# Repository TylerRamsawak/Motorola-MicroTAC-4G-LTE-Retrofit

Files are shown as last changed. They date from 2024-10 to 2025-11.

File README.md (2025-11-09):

# Motorola-MicroTAC-4G-LTE-Retrofit DEPRECATED
<b>Obsolete and no longer works in the real world. I am working on a revision using a quectel bg modem instead. I recommend you stay away from SIMCOM in the future.</b>

A PCB to replace the old hardware inside of a Motorola MicroTAC 9800X and like models that share the same housing with a 4G LTE modem.

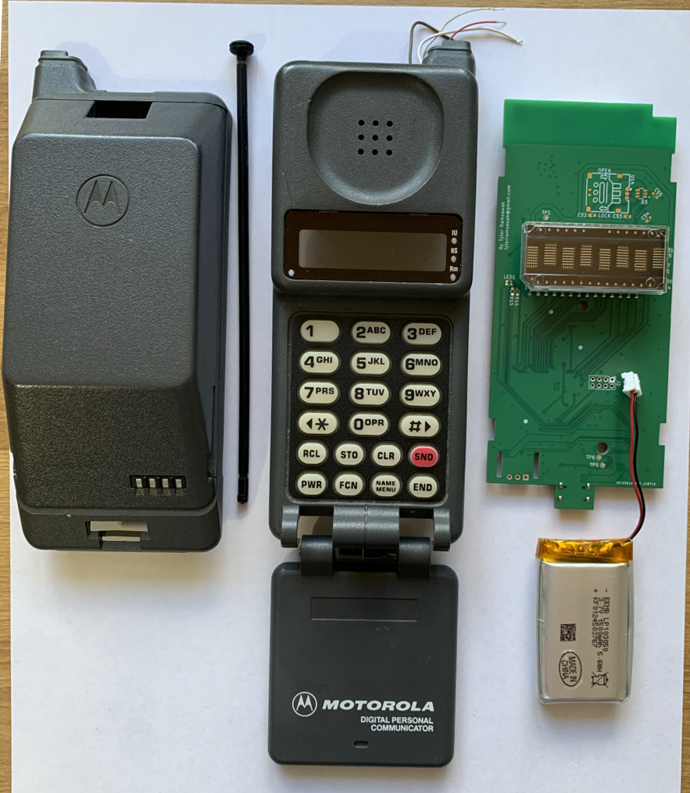
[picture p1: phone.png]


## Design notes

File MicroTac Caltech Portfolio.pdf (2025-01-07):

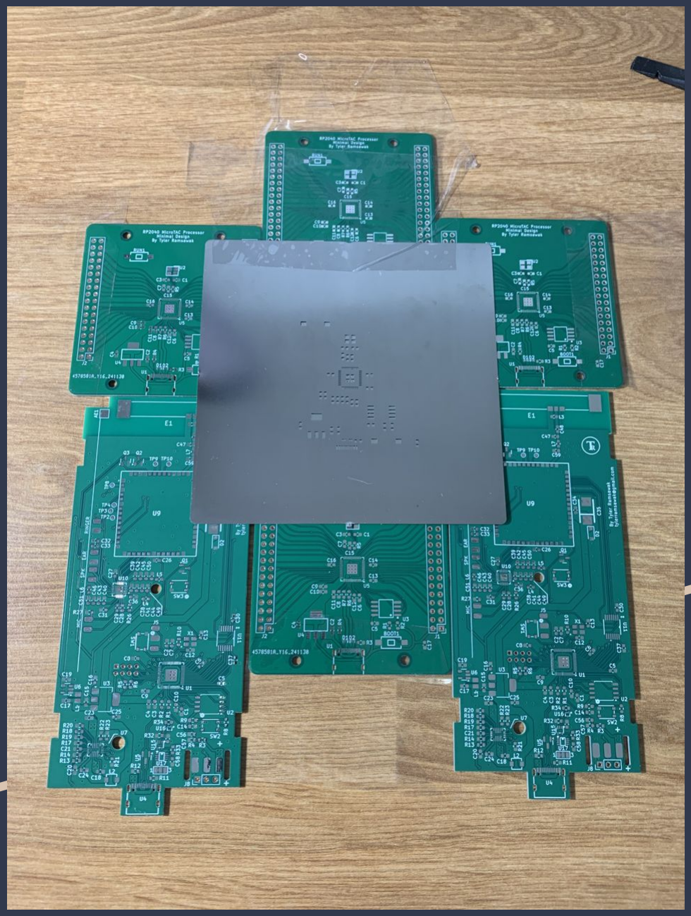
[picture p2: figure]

MicroTAC Assembly Process

### 1. Stencil Framing

First, I frame the prototype by taping down extra PCBs
around it.
This ensures that the
prototype won’t shift around during solder paste
application.

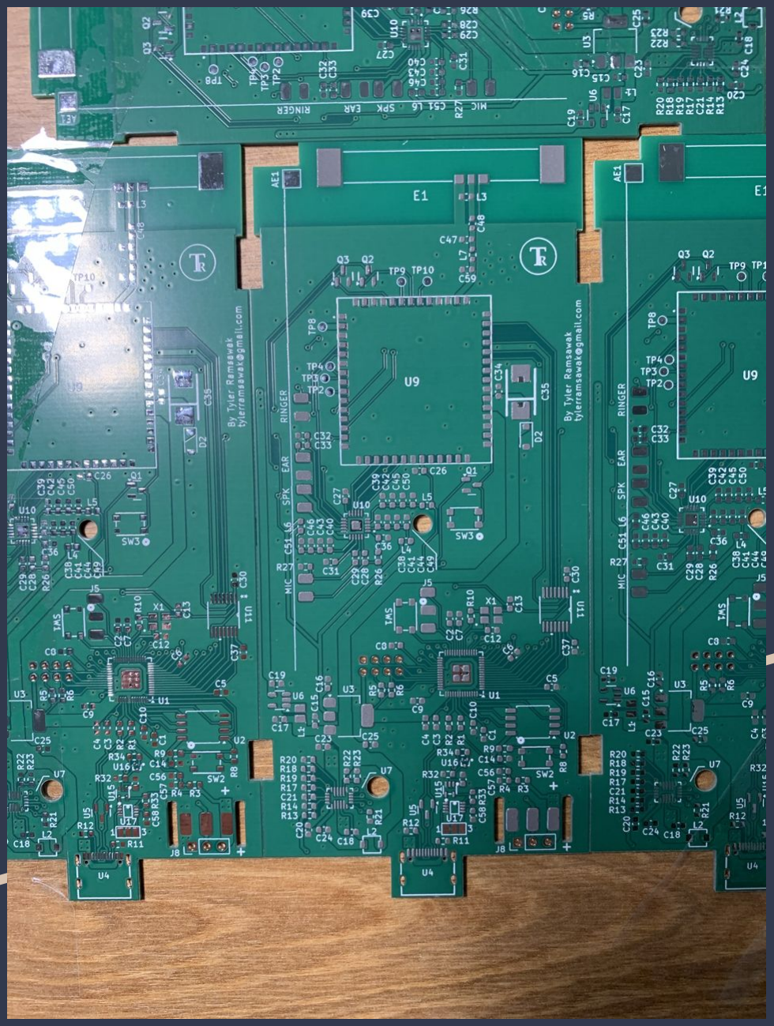
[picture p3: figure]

MicroTAC Assembly Process

### 2. Applying Solder Paste

Using a metal squeegee, I
pull solder paste across the stencil that lays on top of the prototype.
This applies solder paste to the pads of the board.

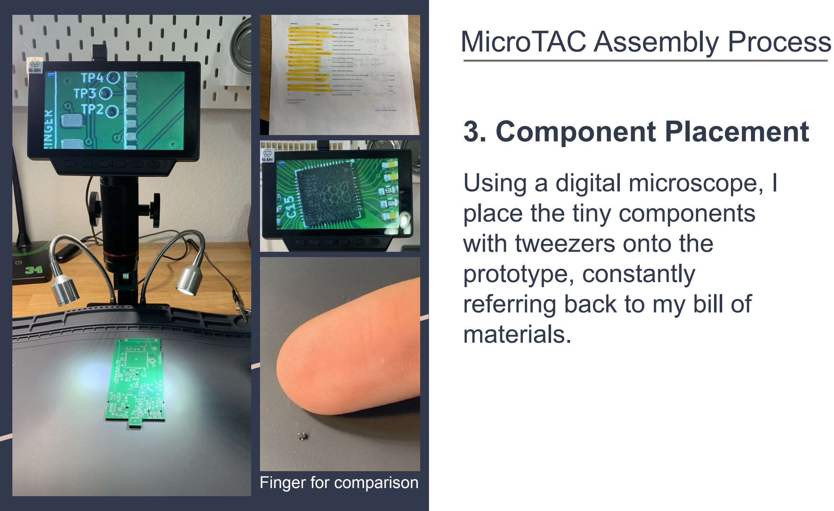
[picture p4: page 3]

MicroTAC Assembly Process

### 3. Component Placement

Using a digital microscope, I place the tiny components
with tweezers onto the
prototype, constantly
referring back to my bill of materials.

Finger for comparison

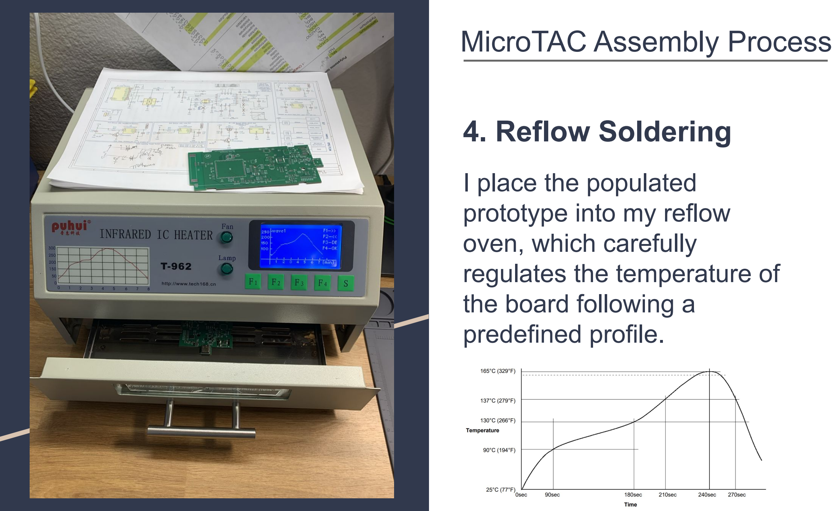
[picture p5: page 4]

MicroTAC Assembly Process

### 4. Reflow Soldering

I place the populated
prototype into my reflow
oven, which carefully
regulates the temperature of the board following a
predefined profile.

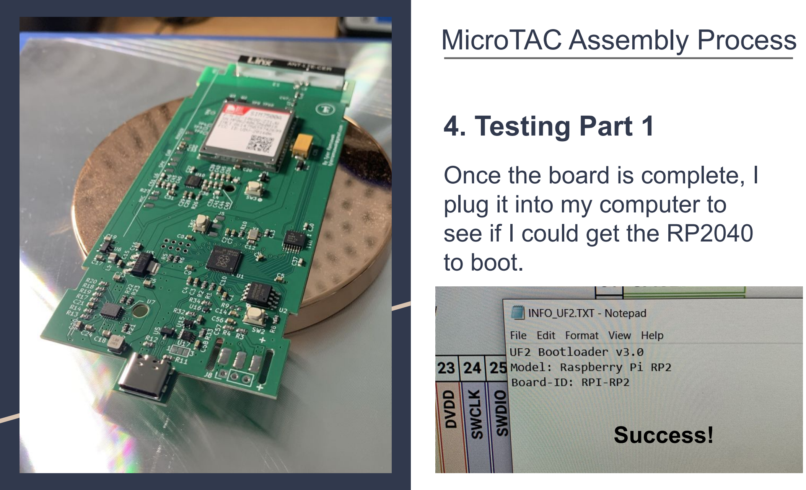
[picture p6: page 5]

MicroTAC Assembly Process

### 4. Testing Part 1

Once the board is complete, I plug it into my computer to see if I could get the RP2040 to boot.

Success!

MicroTAC Assembly Process

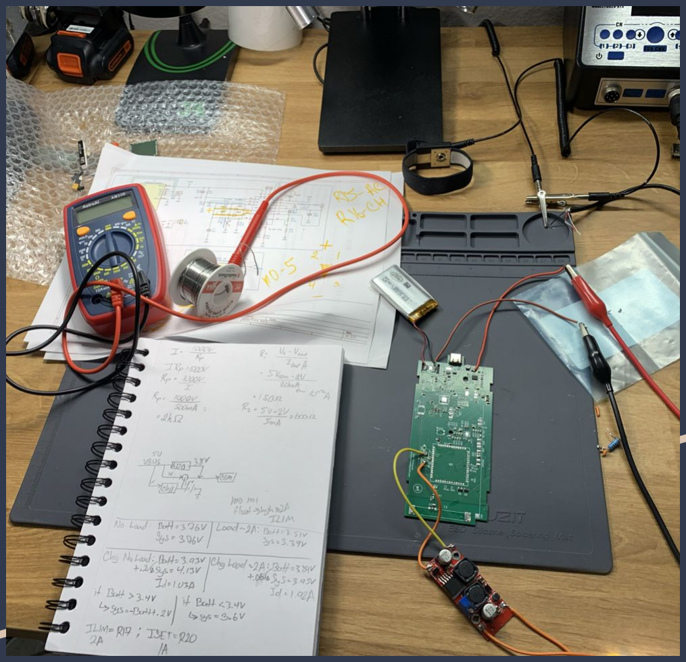
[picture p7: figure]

### 4. Testing Part 2

On a separate barebones
prototype, I aggressively test the charging circuitry and battery protection features by simulating a 2A continuous load condition and recording data with a multimeter.
I compare this data with the formulas in the PMIC
datasheet.

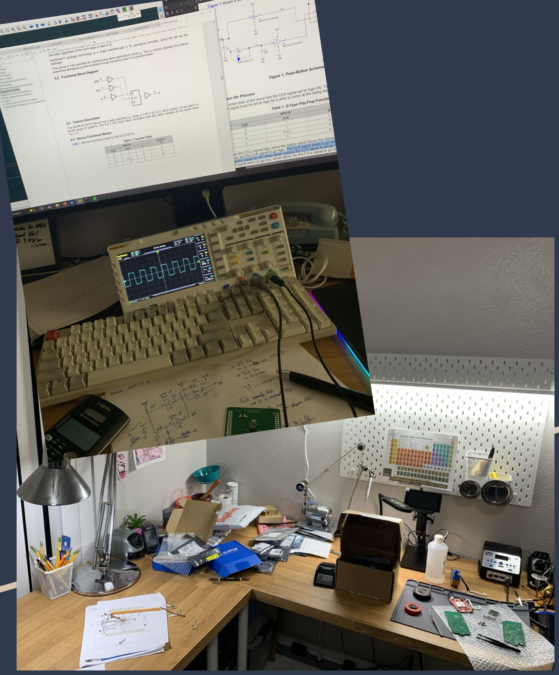
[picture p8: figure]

MicroTAC Assembly Process

### 5. Cleaning

My lab turns into a mess after the assembly and debugging. So, I usually take the rest of the night to clean up and
reorganize my equipment.

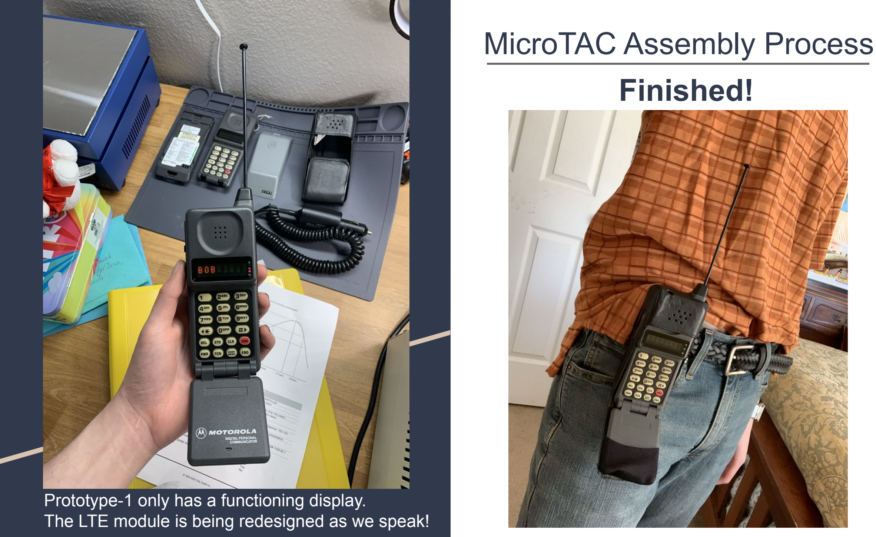
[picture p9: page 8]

MicroTAC Assembly Process

Prototype-1 only has a functioning display.
The LTE module is being redesigned as we speak!

Finished!

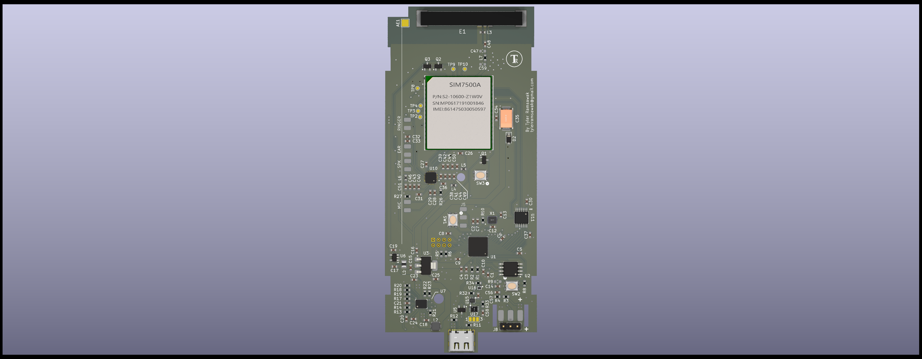
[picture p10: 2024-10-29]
3D_front_populated.png

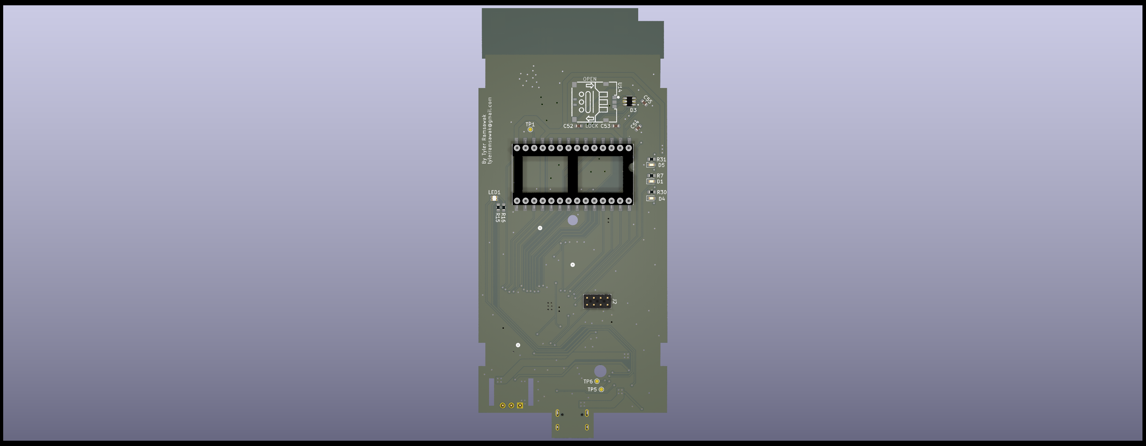
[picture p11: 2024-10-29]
3D_back_populated.png

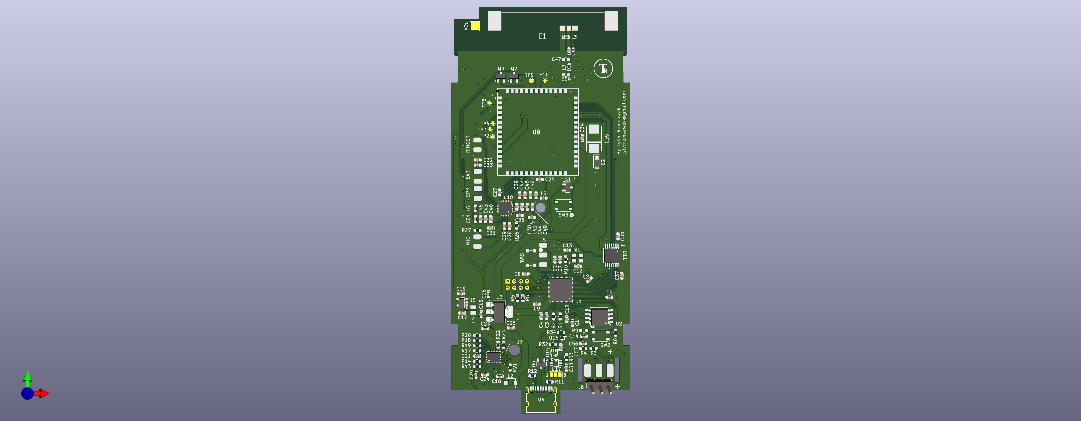
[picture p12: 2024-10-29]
3D_front_np.png

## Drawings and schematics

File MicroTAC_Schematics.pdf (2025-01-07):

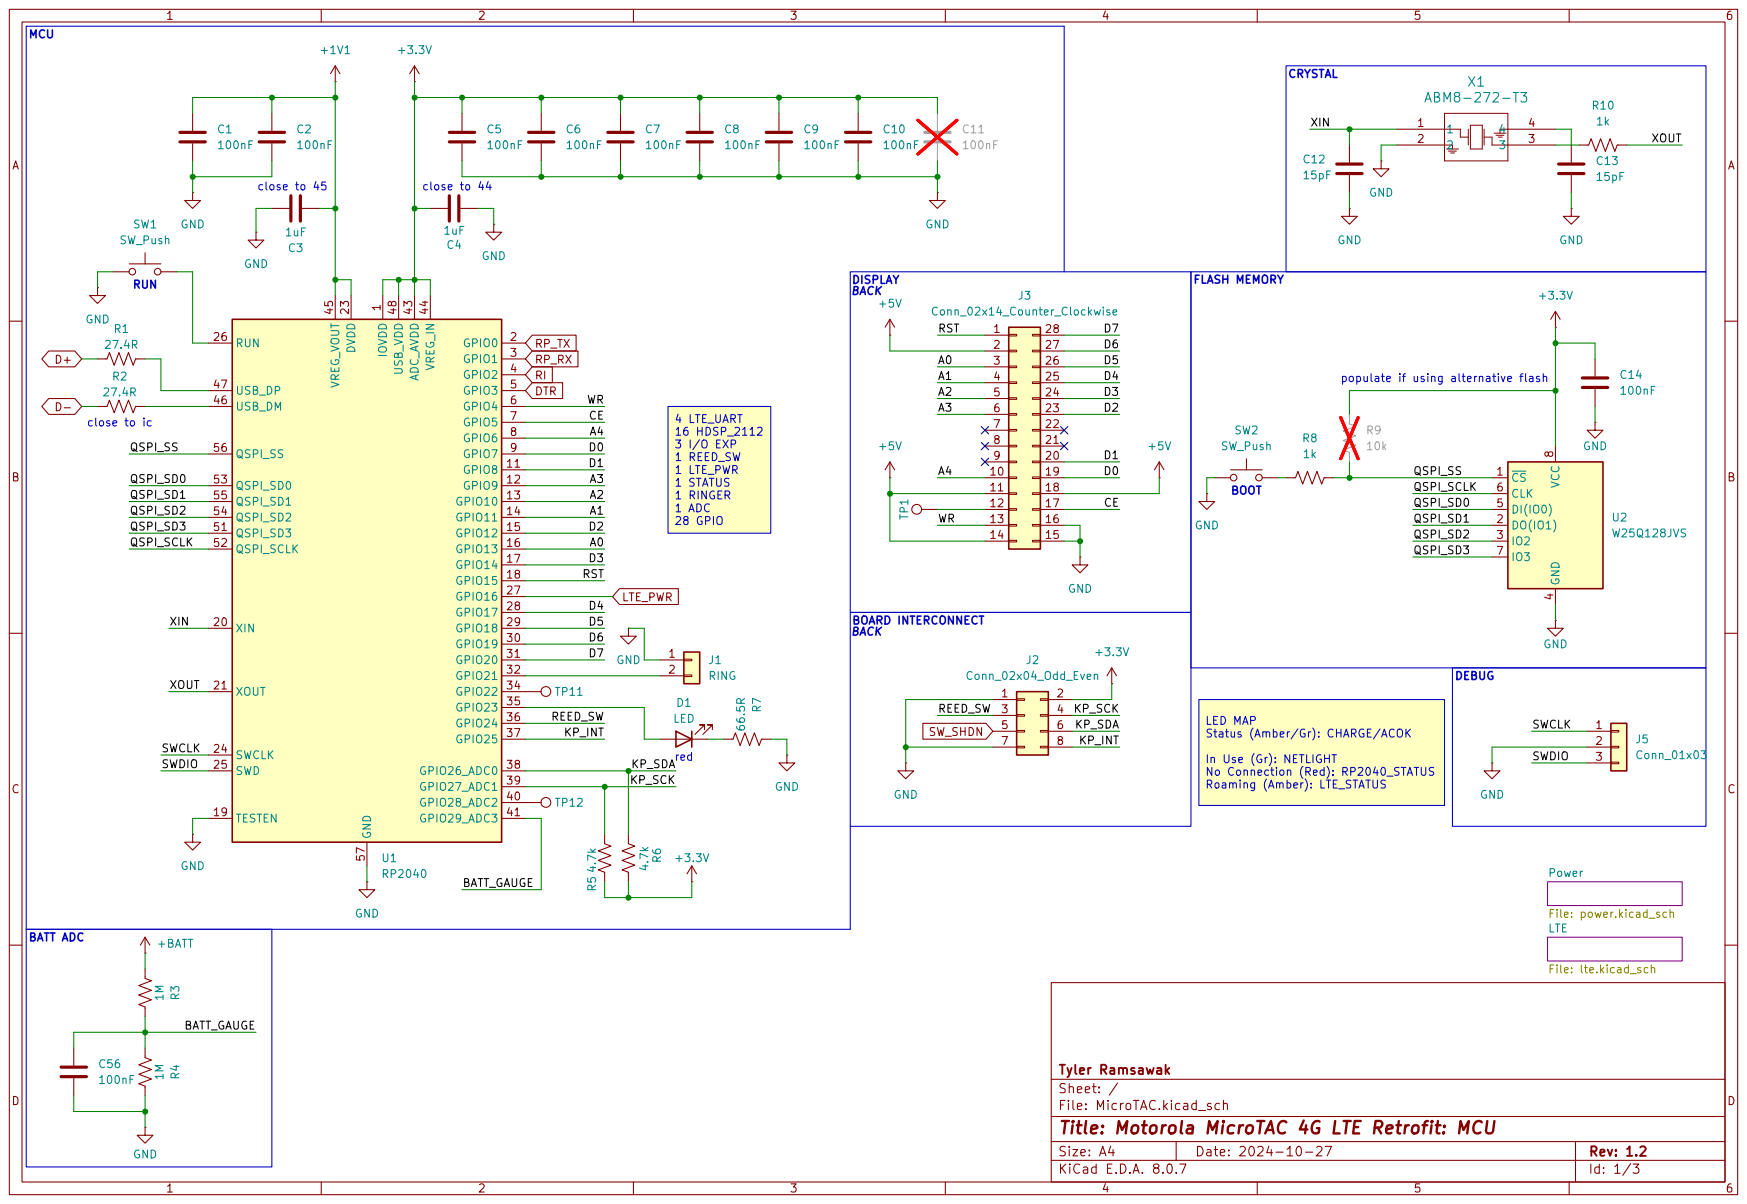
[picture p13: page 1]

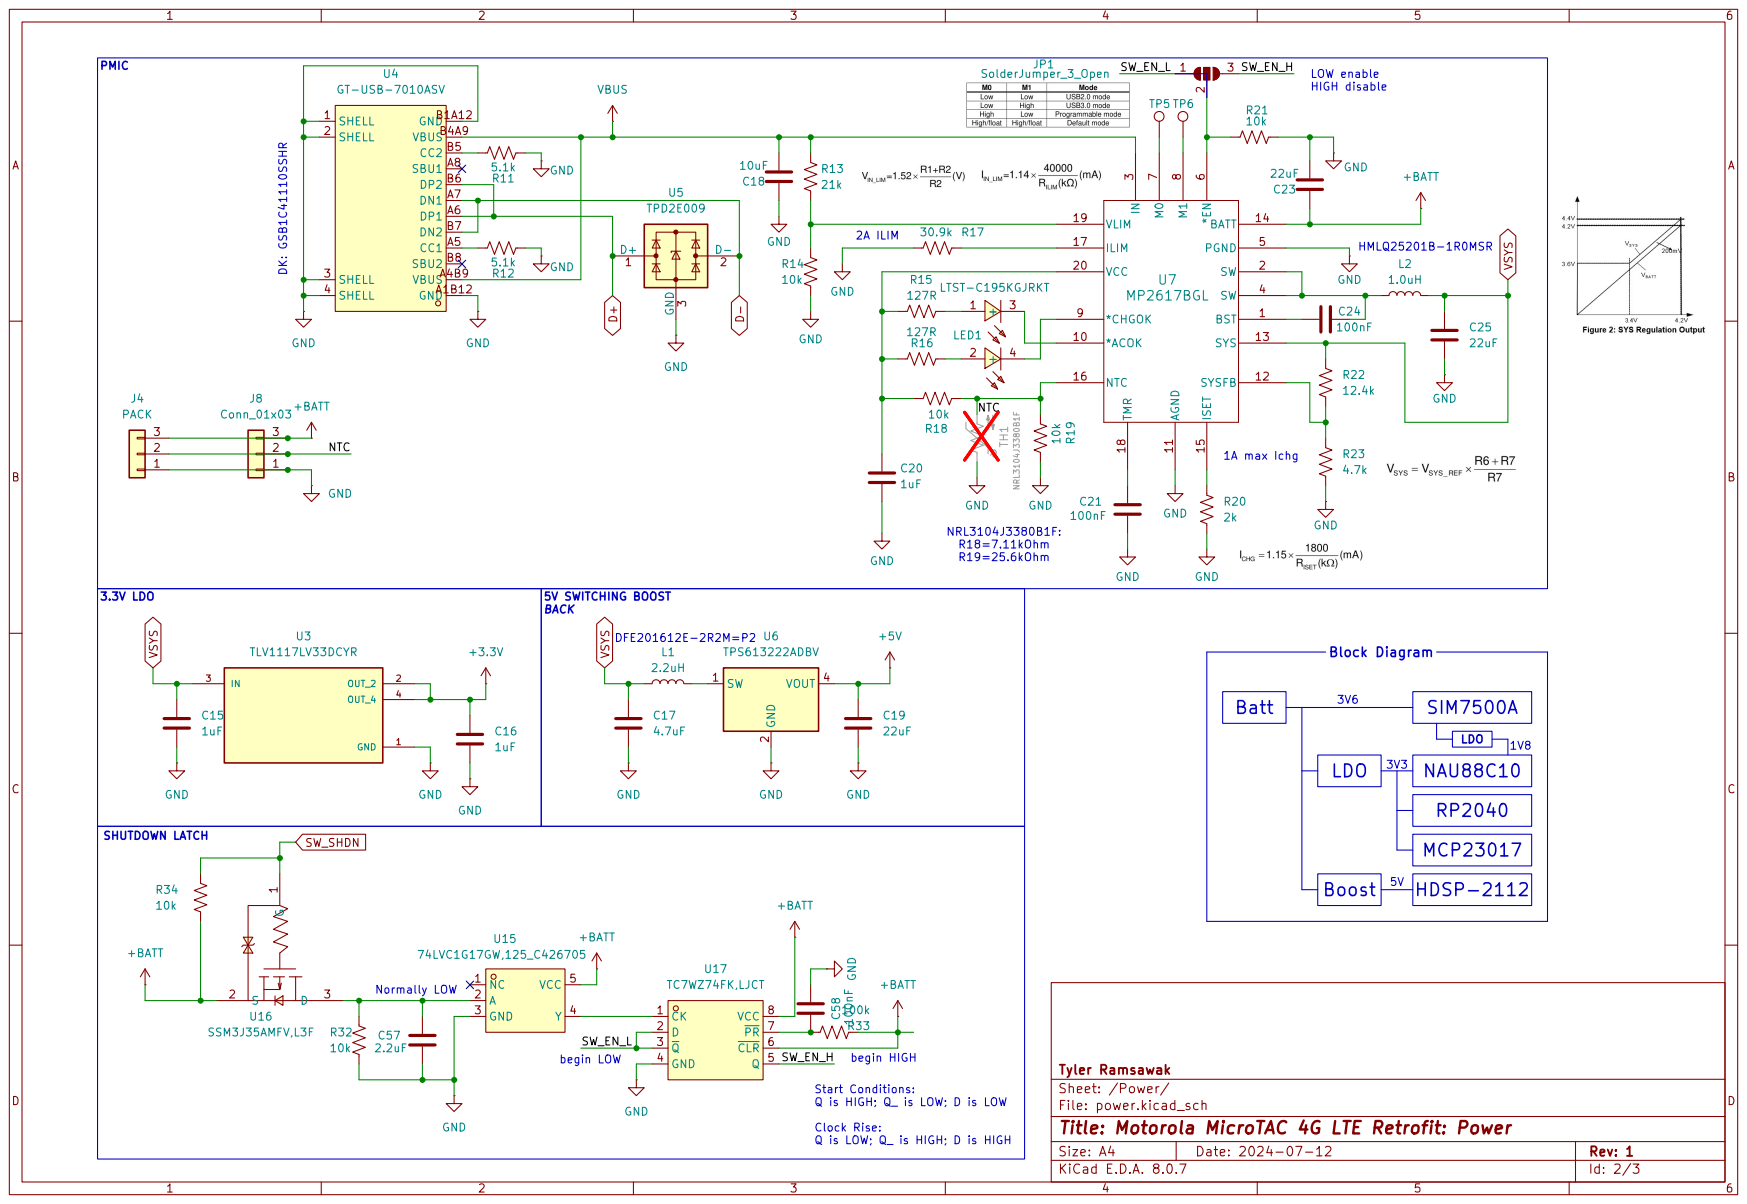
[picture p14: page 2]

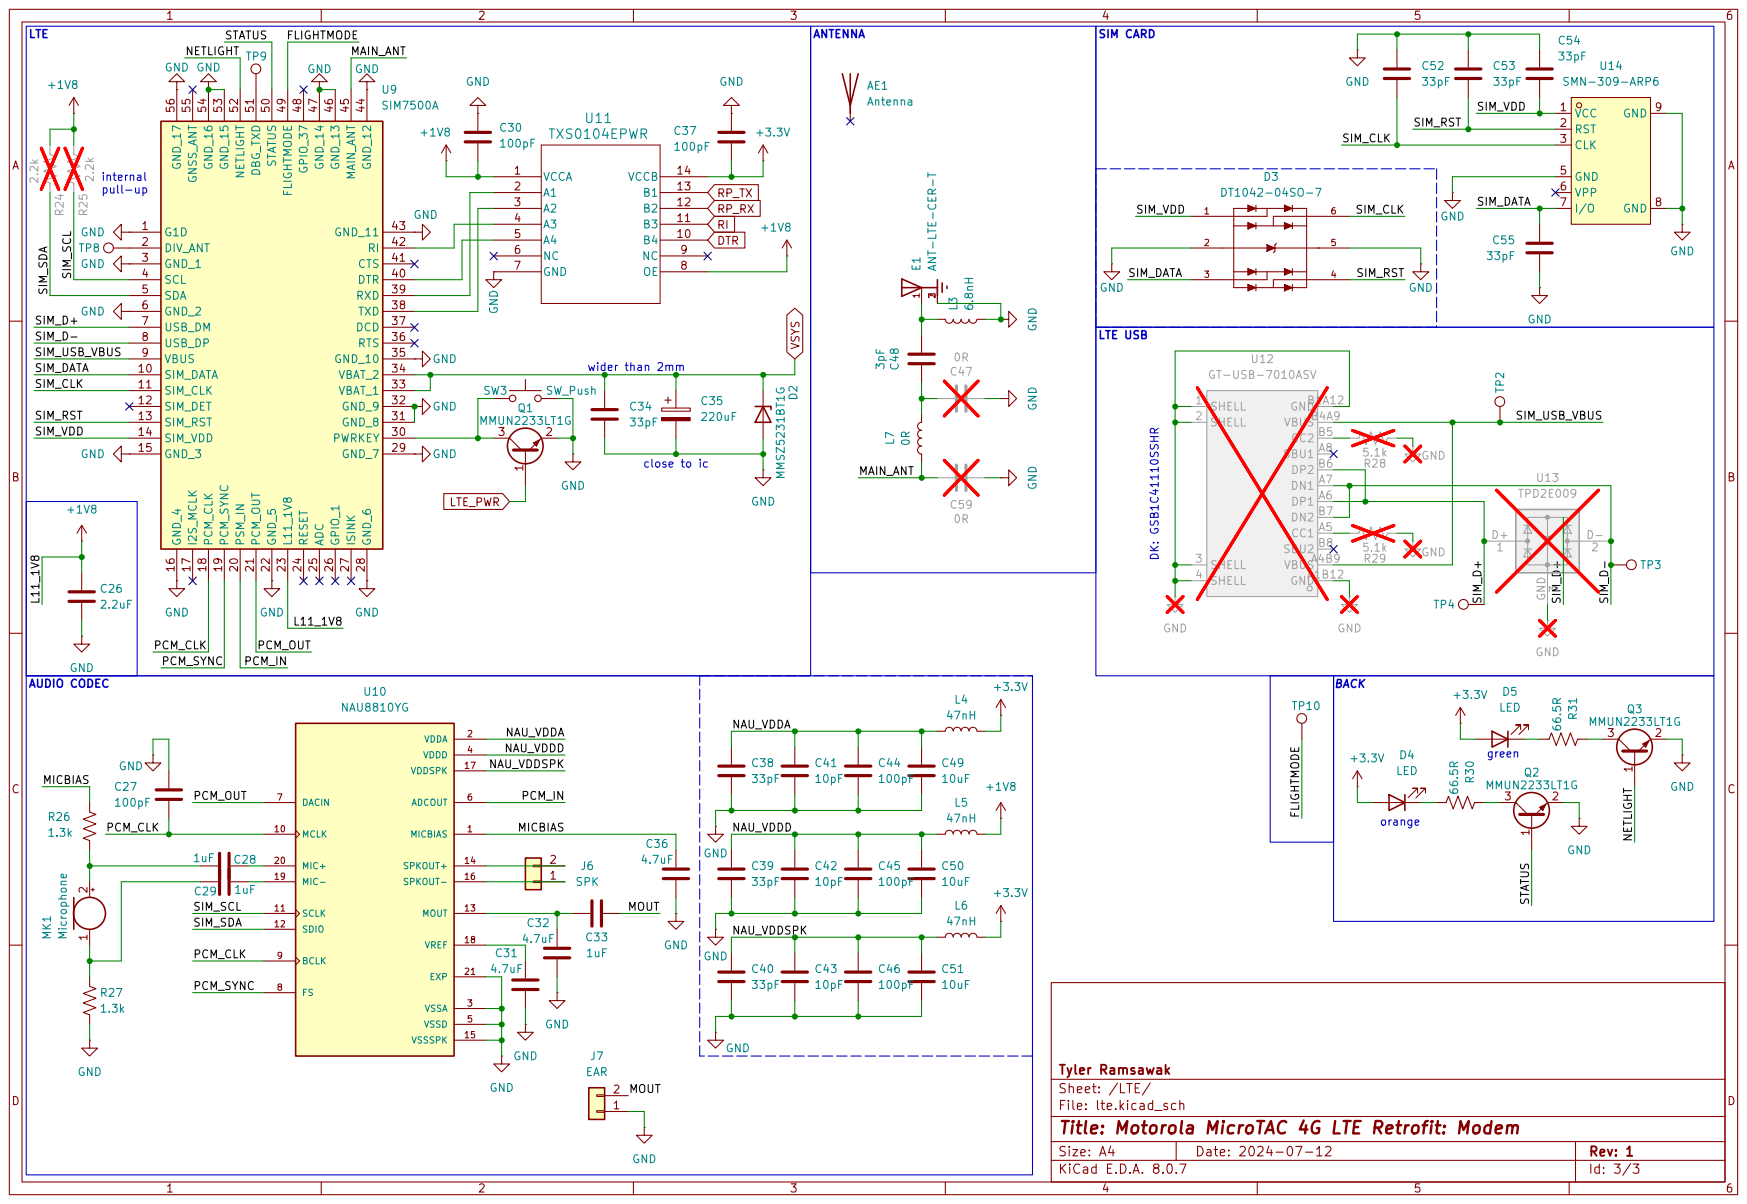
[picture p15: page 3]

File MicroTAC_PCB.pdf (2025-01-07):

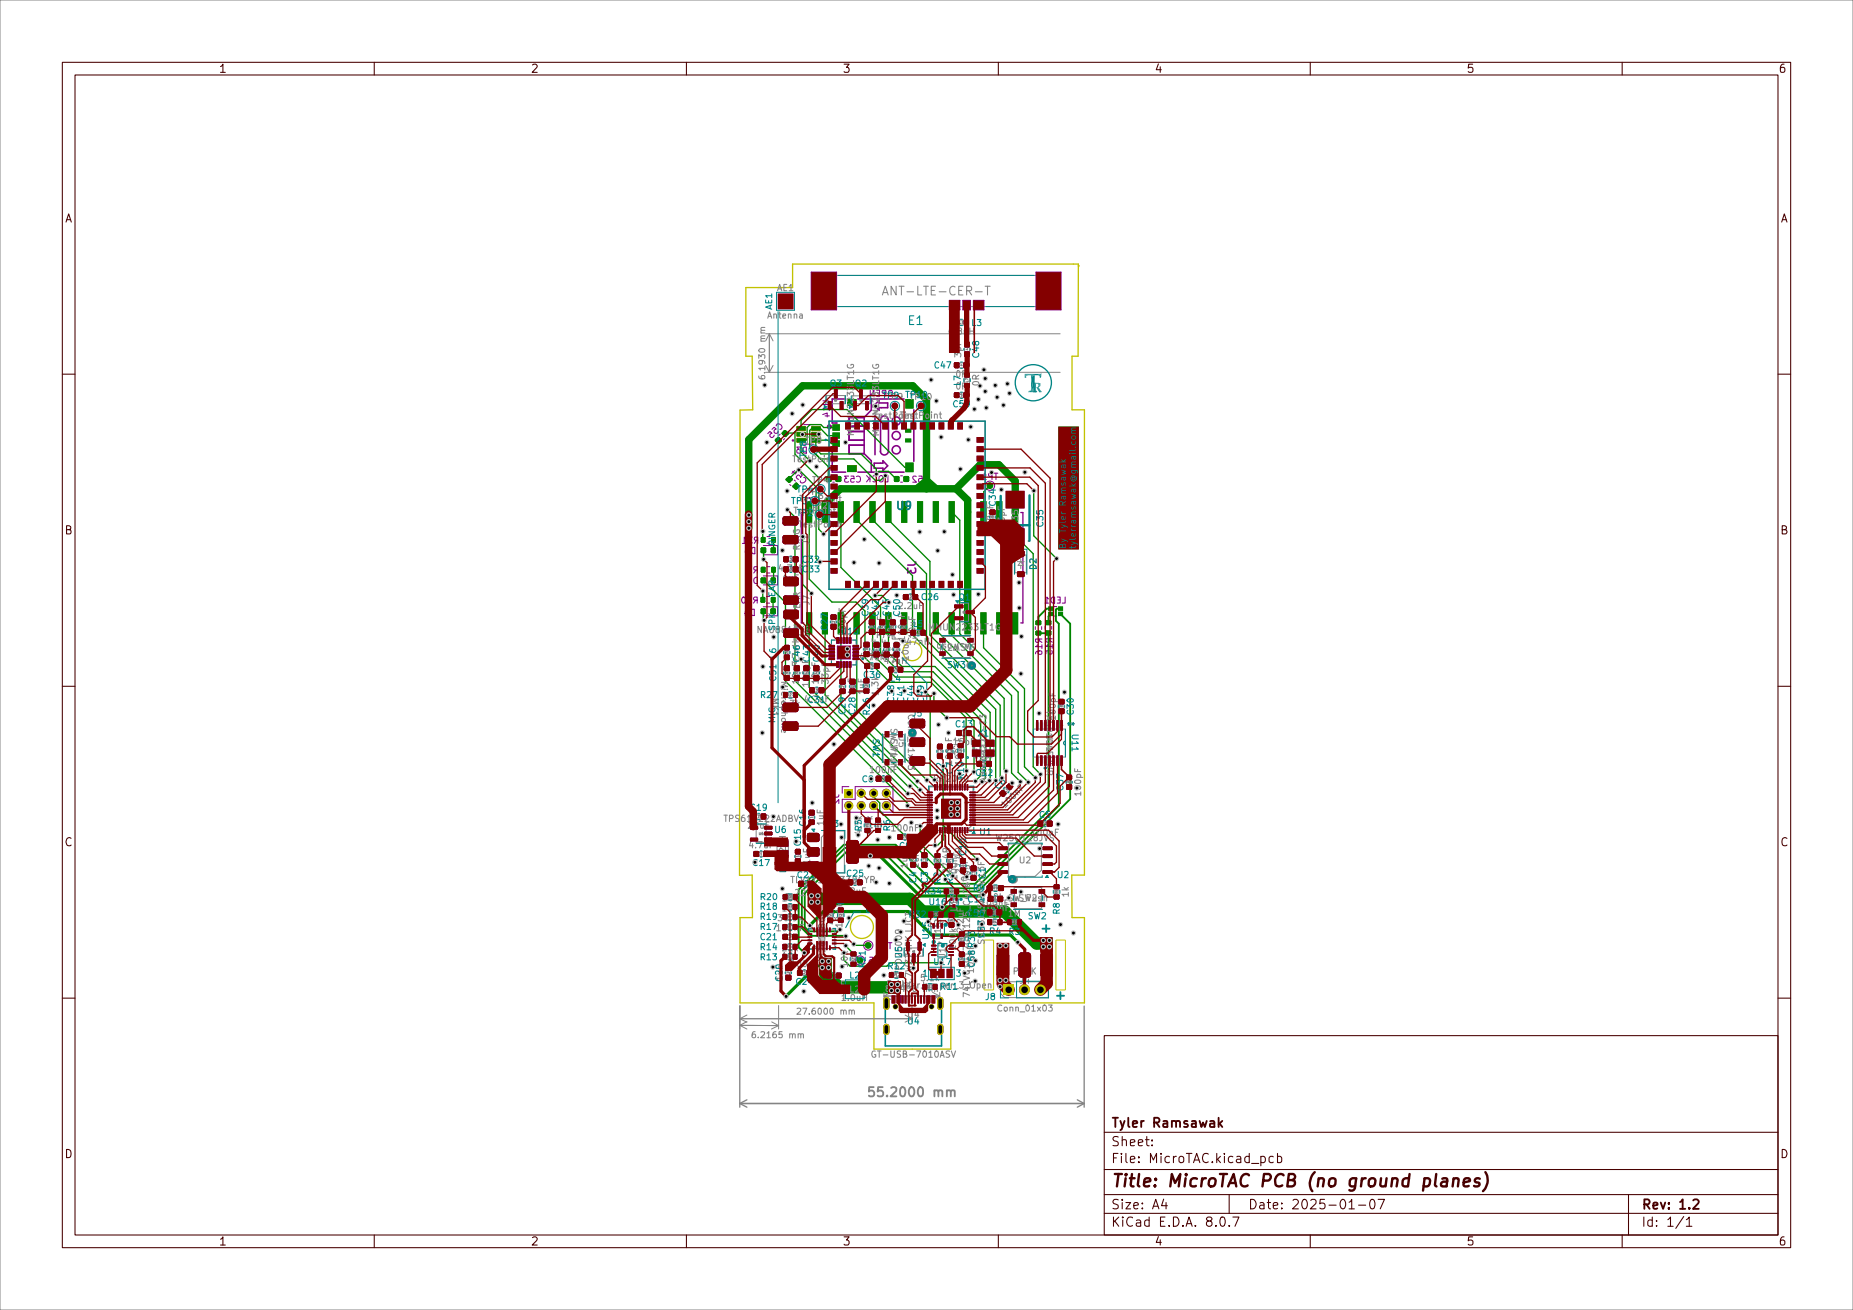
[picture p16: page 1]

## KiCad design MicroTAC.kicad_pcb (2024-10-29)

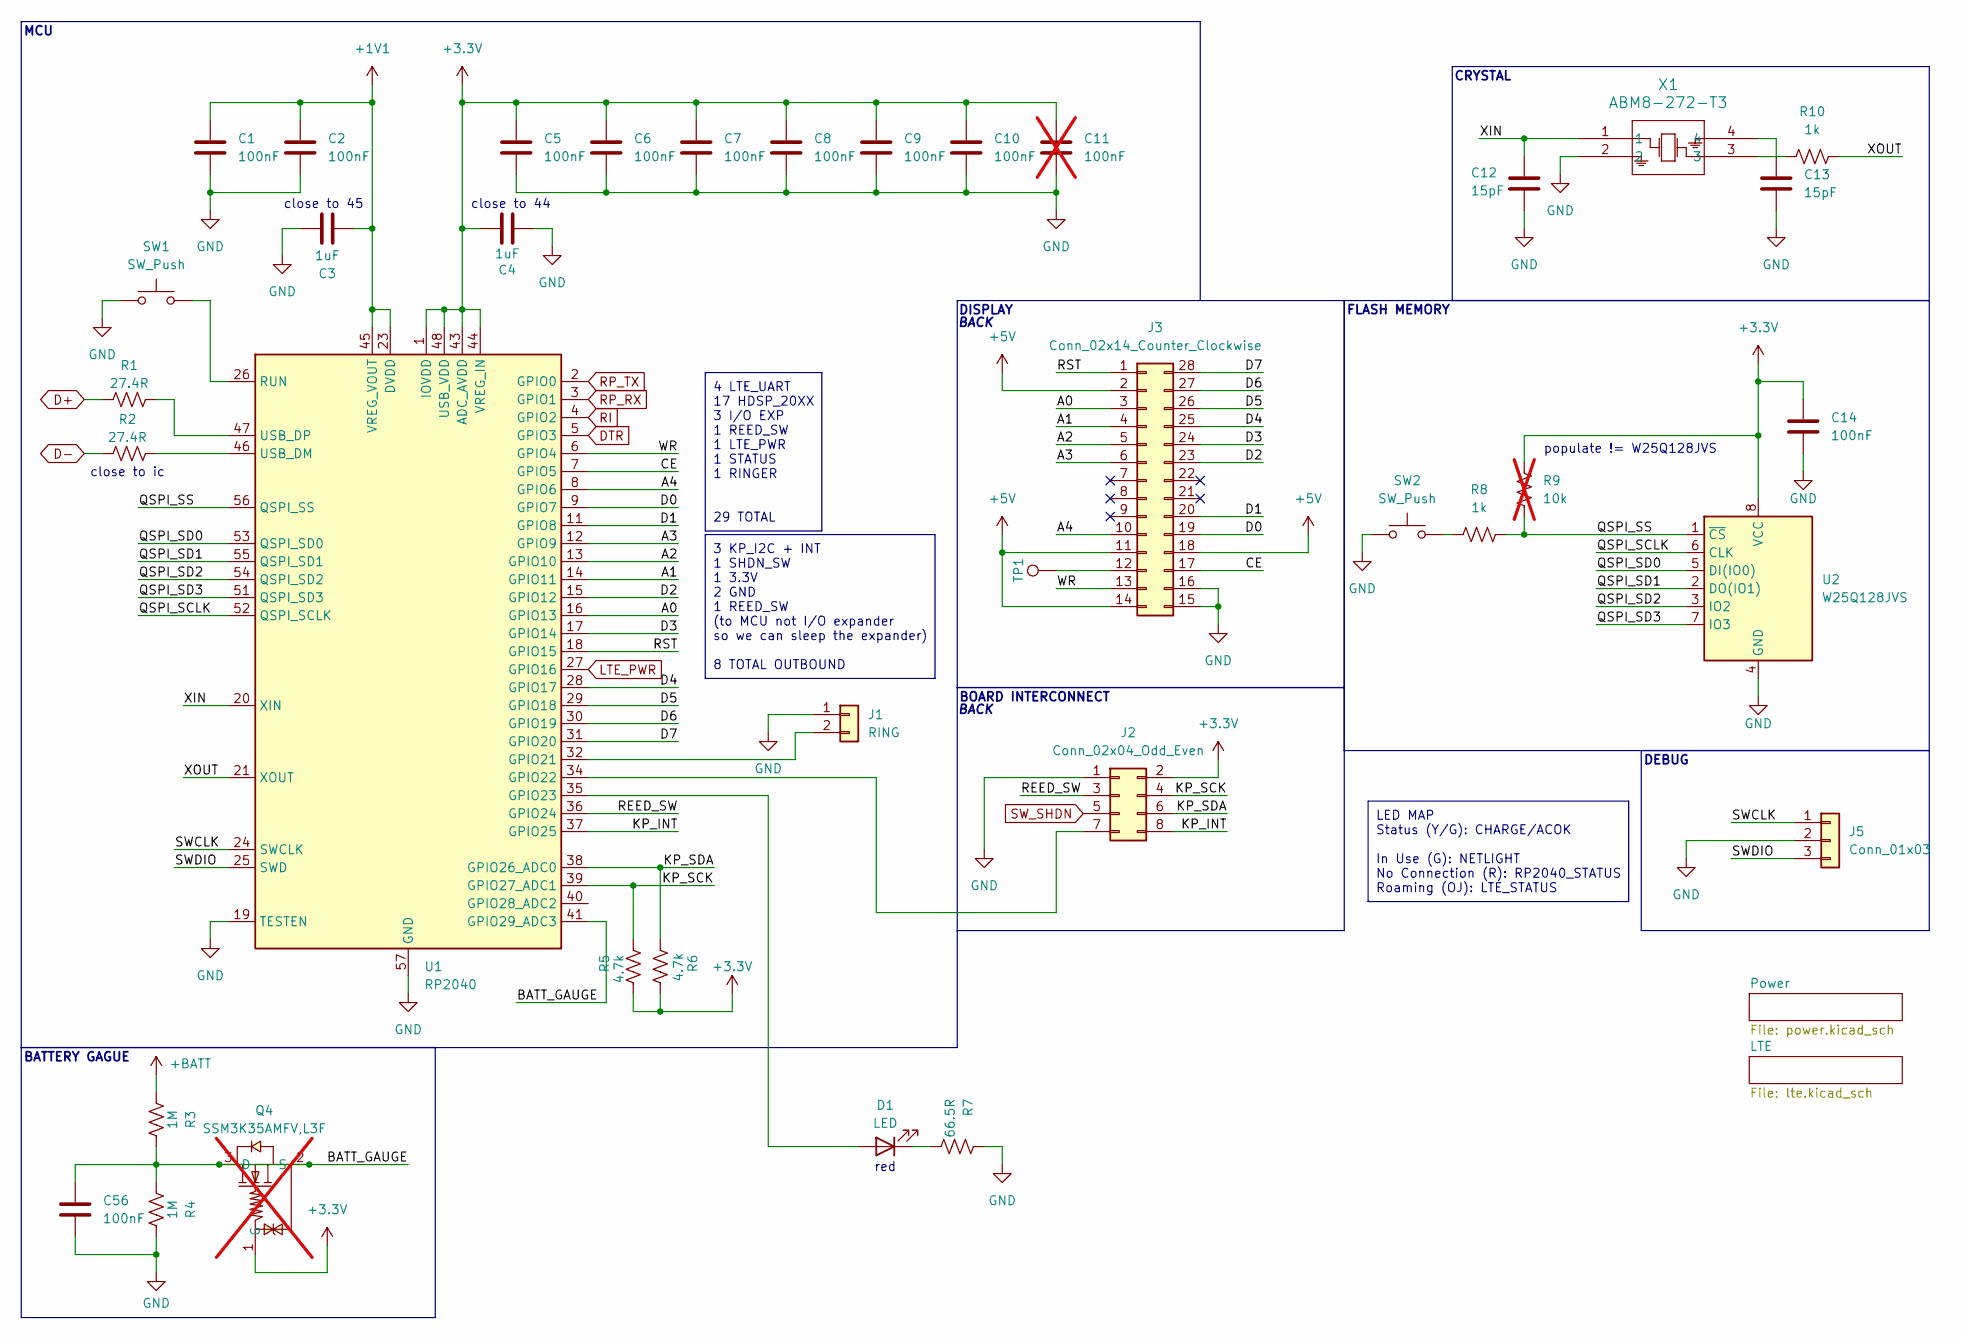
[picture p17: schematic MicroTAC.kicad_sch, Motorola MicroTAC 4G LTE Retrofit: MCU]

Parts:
C1, C2, C5, C6, C7, C8, C9, C10, C14, C56: 100nF; C_0603_1608Metric; LCSC Part # C1591
C3, C4: 1uF; C_0603_1608Metric; LCSC Part # C59782
C11: 100nF; C_0603_1608Metric_Pad1.08x0.95mm_HandSolder; LCSC Part # C1591; not fitted
C12, C13: 15pF; C_0603_1608Metric; LCSC Part # C346207
D1: LED; LED_0603_1608Metric; LCSC Part # C125099
J1: RING; MicroTAC Peripherals
J2: Conn_02x04_Odd_Even; PinHeader_2x04_P2.00mm_Vertical; LCSC Part # C917609
J3: Conn_02x14_Counter_Clockwise; 1108762841105101
J5: Conn_01x03; MicroTAC Debug
Q4: SSM3K35AMFV,L3F; SOT-723_L1.2-W0.8-P0.40-LS1.2-BR; LCSC Part C150155; not fitted
R1, R2: 27.4R; R_0603_1608Metric; LCSC Part # C185346
R3, R4: 1M; R_0603_1608Metric; LCSC Part # C14675
R5, R6: 4.7k; R_0603_1608Metric; LCSC Part # C99782
R7: 66.5R; R_0603_1608Metric; LCSC Part # C245995
R8, R10: 1k; R_0603_1608Metric; LCSC Part # C22548
R9: 10k; R_0603_1608Metric_Pad0.98x0.95mm_HandSolder; not fitted
SW1, SW2: SW_Push; SW4_PTS815_SJM_250_SMTR_LFS_CNK; LCSC Part # C2689510
TP1: TestPoint; TestPoint_Pad_D1.0mm
U1: RP2040; QFN-56-1EP_7x7mm_P0.4mm_EP3.2x3.2mm; LCSC Part # C2040
U2: W25Q128JVS; SOIC-8_5.23x5.23mm_P1.27mm; LCSC Part # C97521
X1: ABM8-272-T3; ABM8-272-T3_ABR; LCSC Part # C20625731

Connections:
+1V1: C1.1, C2.1, C3.1, U1.23 (DVDD), U1.45 (VREG_VOUT), U1.50 (DVDD)
+3.3V: C4.1, C5.1, C6.1, C7.1, C8.1, C9.1, C10.1, C11.1, C14.1, J2.2, Q4.1 (G), R5.2, R6.2, R9.1, U1.1 (IOVDD), U1.10 (IOVDD), U1.22 (IOVDD), U1.33 (IOVDD), U1.42 (IOVDD), U1.43 (ADC_AVDD), U1.44 (VREG_IN), U1.48 (USB_VDD), U1.49 (IOVDD), U2.8 (VCC); also elsewhere on the board
+5V: J3.2, J3.11, J3.14, J3.18; also elsewhere on the board
+BATT: R3.1; also elsewhere on the board
/A0: J3.3, U1.16 (GPIO13)
/A1: J3.4, U1.14 (GPIO11)
/A2: J3.5, U1.13 (GPIO10)
/A3: J3.6, U1.12 (GPIO9)
/A4: J3.10, U1.8 (GPIO6)
/BATT_GAUGE: C56.1, Q4.2 (S), Q4.3 (D), R3.2, R4.1, U1.41 (GPIO29_ADC3)
/CE: J3.17, U1.7 (GPIO5)
/D0: J3.19, U1.9 (GPIO7)
/D1: J3.20, U1.11 (GPIO8)
/D2: J3.23, U1.15 (GPIO12)
/D3: J3.24, U1.17 (GPIO14)
/D4: J3.25, U1.28 (GPIO17)
/D5: J3.26, U1.29 (GPIO18)
/D6: J3.27, U1.30 (GPIO19)
/D7: J3.28, U1.31 (GPIO20)
/KP_INT: J2.8, U1.37 (GPIO25)
/KP_SCK: J2.4, R5.1, U1.39 (GPIO27_ADC1)
/KP_SDA: J2.6, R6.1, U1.38 (GPIO26_ADC0)
/QSPI_SCLK: U1.52 (QSPI_SCLK), U2.6 (CLK)
/QSPI_SD0: U1.53 (QSPI_SD0), U2.5 (DI(IO0))
/QSPI_SD1: U1.55 (QSPI_SD1), U2.2 (DO(IO1))
/QSPI_SD2: U1.54 (QSPI_SD2), U2.3 (IO2)
/QSPI_SD3: U1.51 (QSPI_SD3), U2.7 (IO3)
/QSPI_SS: R8.2, R9.2, U1.56 (QSPI_SS), U2.1 (~CS)
/REED_SW: J2.3, U1.36 (GPIO24)
/RST: J3.1, U1.18 (GPIO15)
/SWCLK: J5.1, U1.24 (SWCLK)
/SWDIO: J5.3, U1.25 (SWD)
/WR: J3.13, U1.6 (GPIO4)
/XIN: C12.2, U1.20 (XIN), X1.1
/XOUT: R10.2, U1.21 (XOUT)
D+: R1.1; also elsewhere on the board
D-: R2.1; also elsewhere on the board
DTR: U1.5 (GPIO3); also elsewhere on the board
GND: C1.2, C2.2, C3.2, C4.2, C5.2, C6.2, C7.2, C8.2, C9.2, C10.2, C11.2, C12.1, C13.1, C14.2, C56.2, J1.1, J2.1, J3.15, J3.16, J5.2, R4.2, R7.2, SW1.1, SW2.1, U1.19 (TESTEN), U1.57 (GND), U2.4 (GND), X1.2; also elsewhere on the board
LTE_PWR: U1.27 (GPIO16); also elsewhere on the board
unnamed: C13.2, X1.4
unnamed: D1.2 (A), U1.35 (GPIO23)
unnamed: D1.1 (K), R7.1
unnamed: J1.2, U1.32 (GPIO21)
unnamed: J2.7, U1.34 (GPIO22)
unnamed: J3.12, TP1.1
unnamed: R8.1, SW2.2
unnamed: R10.1, X1.3
unnamed: SW1.2, U1.26 (RUN)
unnamed: R2.2, U1.46 (USB_DM)
unnamed: R1.2, U1.47 (USB_DP)
RI: U1.4 (GPIO2); also elsewhere on the board
RP_RX: U1.3 (GPIO1); also elsewhere on the board
RP_TX: U1.2 (GPIO0); also elsewhere on the board
SW_SHDN: J2.5; also elsewhere on the board

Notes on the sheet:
4 LTE_UART 17 HDSP_20XX 3 I/O EXP 1 REED_SW 1 LTE_PWR 1 STATUS 1 RINGER 29 TOTAL
LED MAP Status (Y/G): CHARGE/ACOK In Use (G): NETLIGHT No Connection (R): RP2040_STATUS Roaming (OJ): LTE_STATUS
3 KP_I2C + INT 1 SHDN_SW 1 3.3V 2 GND 1 REED_SW (to MCU not I/O expander so we can sleep the expander) 8 TOTAL OUTBOUND
BACK
close to 45
CRYSTAL
close to ic
red
DEBUG
MCU
BOARD INTERCONNECT
DISPLAY
FLASH MEMORY
populate != W25Q128JVS
BATTERY GAGUE
close to 44

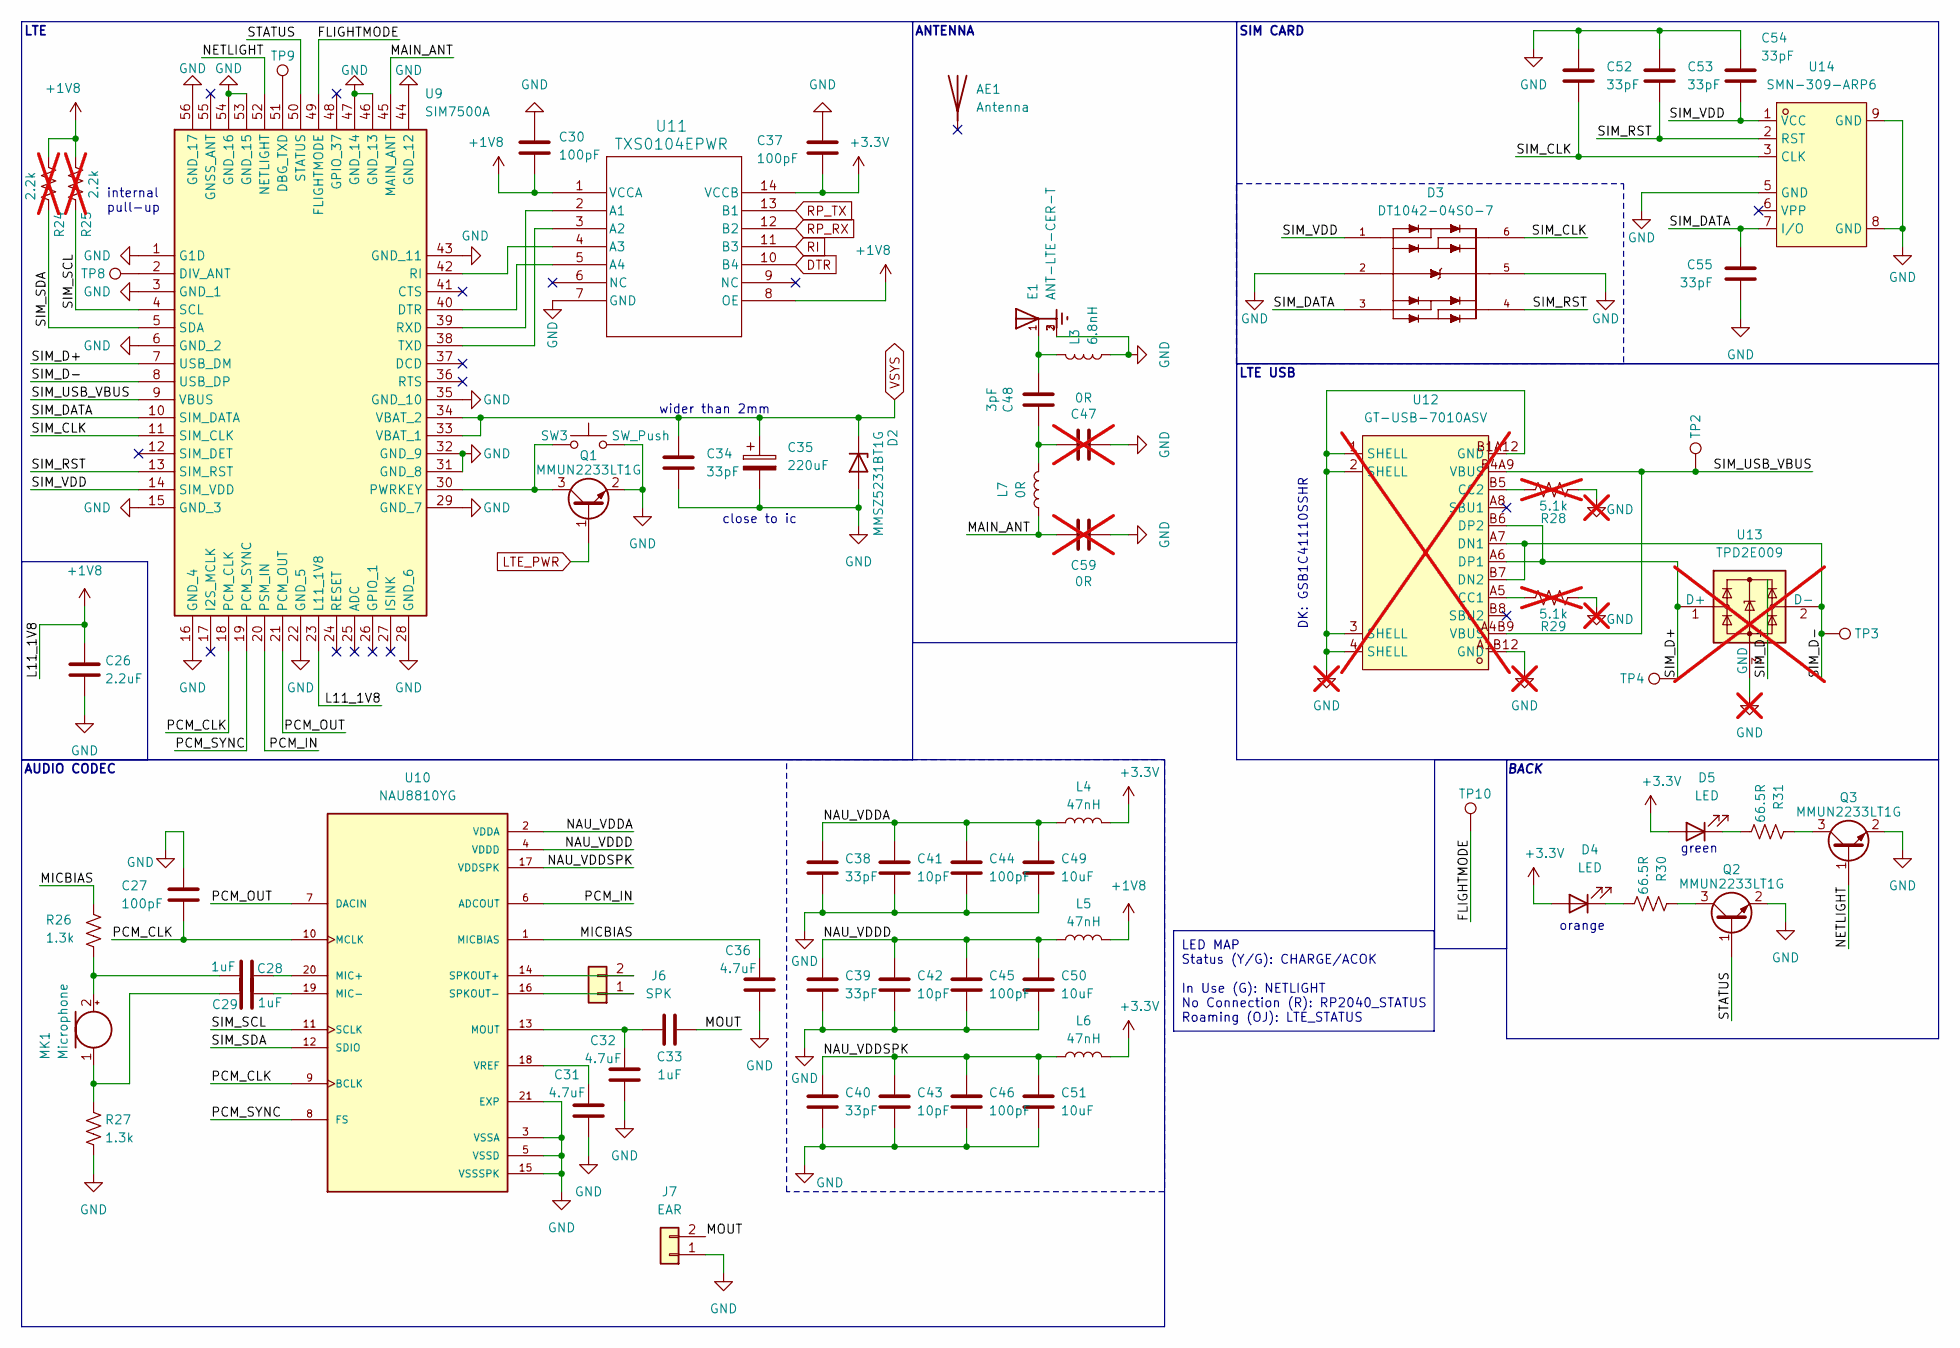
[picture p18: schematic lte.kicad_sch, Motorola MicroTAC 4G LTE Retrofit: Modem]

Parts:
AE1: Antenna; TestPoint_Pad_2.5x2.5mm
C26: 2.2uF; C_0603_1608Metric; LCSC Part # C100082
C27, C30, C37, C44, C45, C46: 100pF; C_0603_1608Metric; LCSC Part # C1852828
C28, C29, C33: 1uF; C_0603_1608Metric; LCSC Part # C59782
C31, C32, C36: 4.7uF; C_0603_1608Metric; LCSC Part # C107368
C34, C38, C39, C40, C52, C53, C54, C55: 33pF; C_0603_1608Metric; LCSC Part # C2169365
C35: 220uF; CASE-D_7343; LCSC Part # C8024
C41, C42, C43: 10pF; C_0603_1608Metric; LCSC Part # C2170082
C47, C59: 0R; C_0603_1608Metric; not fitted
C48: 3pF; C_0603_1608Metric; LCSC Part $ C46219
C49, C50, C51: 10uF; C_0603_1608Metric; LCSC Part # C3039698
D2: MMSZ5231BT1G; D_SOD-123; LCSC Part # C66198
D3: DT1042-04SO-7; SOT95P285X140-6N; PARTREV 2-2; LCSC Part # C460064
D4: LED; LED_0603_1608Metric; LCSC Part # C160478
D5: LED; LED_0603_1608Metric; LCSC Part # C125098
E1: ANT-LTE-CER-T; XDCR_ANT-LTE-CER-T; PARTREV A
J6: SPK; MicroTAC Peripherals
J7: EAR; MicroTAC Peripherals
L3: 6.8nH; L_0603_1608Metric; LCSC Part # C49447
L4, L5, L6: 47nH; L_0603_1608Metric; LCSC Part # C29683
L7: 0R; R_0603_1608Metric; LCSC Part # C95177
MK1: Microphone; MicroTAC Peripherals
Q1, Q2, Q3: MMUN2233LT1G; SOT-23; LCSC Part # C86932
R24, R25: 2.2k; R_0603_1608Metric_Pad0.98x0.95mm_HandSolder; not fitted
R26, R27: 1.3k; R_0603_1608Metric; LCSC Part # C125319
R28, R29: 5.1k; R_0603_1608Metric; LCSC Part # C105580; not fitted
R30, R31: 66.5R; R_0603_1608Metric; LCSC Part # C245995
SW3: SW_Push; SW4_PTS815_SJM_250_SMTR_LFS_CNK; LCSC Part # C2689510
TP2, TP3, TP4, TP8, TP9, TP10: TestPoint; TestPoint_Pad_D1.0mm
U9: SIM7500A; Manufacturer_Part_Number SIM7500A; LCSC Part # C126258
U10: NAU8810YG; QFN50P400X400X80-21N; PARTREV 2.8; LCSC Part # C2613464
U11: TXS0104EPWR; PW14; LCSC Part # C44955
U12: GT-USB-7010ASV; USB-C-SMD_G-SWITCH_GT-USB-7010ASV; LCSC Part C2988369; not fitted
U13: TPD2E009; SOT-23; LCSC Part # C2871371; not fitted
U14: SMN-309-ARP6; TF-CARD_XUNPU_SMN-309-ARP6; LCSC Part C5221432

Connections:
+1V8: C26.2, C30.2, L5.2, R24.1, R25.1, U9.23 (L11_1V8), U11.1 (VCCA), U11.8 (OE)
+3.3V: C37.2, D4.2 (A), D5.2 (A), L4.2, L6.2, U11.14 (VCCB); also elsewhere on the board
/LTE/FLIGHTMODE: TP10.1, U9.49 (FLIGHTMODE)
/LTE/MAIN_ANT: C59.1, L7.1, U9.45 (MAIN_ANT)
/LTE/MICBIAS: C36.2, R26.2, U10.1 (MICBIAS)
/LTE/MOUT: C33.1, J7.2
/LTE/NAU_VDDA: C38.1, C41.1, C44.1, C49.1, L4.1, U10.2 (VDDA)
/LTE/NAU_VDDD: C39.1, C42.1, C45.1, C50.1, L5.1, U10.4 (VDDD)
/LTE/NAU_VDDSPK: C40.1, C43.1, C46.1, C51.1, L6.1, U10.17 (VDDSPK)
/LTE/NETLIGHT: Q3.1 (B), U9.52 (NETLIGHT)
/LTE/PCM_CLK: C27.1, U9.18 (PCM_CLK), U10.9 (BCLK), U10.10 (MCLK)
/LTE/PCM_IN: U9.20 (PSM_IN), U10.6 (ADCOUT)
/LTE/PCM_OUT: U9.21 (PCM_OUT), U10.7 (DACIN)
/LTE/PCM_SYNC: U9.19 (PCM_SYNC), U10.8 (FS)
/LTE/SIM_CLK: C52.2, D3.6, U9.11 (SIM_CLK), U14.3 (CLK)
/LTE/SIM_D+: TP4.1, U9.7 (USB_DM), U12.A6 (DP1), U12.B6 (DP2), U13.1 (D+)
/LTE/SIM_D-: TP3.1, U9.8 (USB_DP), U12.A7 (DN1), U12.B7 (DN2), U13.2 (D-)
/LTE/SIM_DATA: C55.1, D3.3, U9.10 (SIM_DATA), U14.7 (I/O)
/LTE/SIM_RST: C53.2, D3.4, U9.13 (SIM_RST), U14.2 (RST)
/LTE/SIM_SCL: R25.2, U9.4 (SCL), U10.11 (SCLK)
/LTE/SIM_SDA: R24.2, U9.5 (SDA), U10.12 (SDIO)
/LTE/SIM_USB_VBUS: TP2.1, U9.9 (VBUS), U12.A4B9 (VBUS), U12.B4A9 (VBUS)
/LTE/SIM_VDD: C54.2, D3.1, U9.14 (SIM_VDD), U14.1 (VCC)
/LTE/STATUS: Q2.1 (B), U9.50 (STATUS)
DTR: U11.10 (B4); also elsewhere on the board
GND: C26.1, C27.2, C30.1, C31.1, C32.1, C34.2, C35.2, C36.1, C37.1, C38.2, C39.2, C40.2, C41.2, C42.2, C43.2, C44.2, C45.2, C46.2, C47.1, C49.2, C50.2, C51.2, C52.1, C53.1, C54.1, C55.2, C59.2, D2.2 (A), D3.2, D3.5, E1.2, E1.3, J7.1, L3.1, Q1.2 (E), Q2.2 (E), Q3.2 (E), R27.1, R28.1, R29.1, SW3.2, U9.1 (G1D), U9.3 (GND_1), U9.6 (GND_2), U9.15 (GND_3), U9.16 (GND_4), U9.22 (GND_5), U9.28 (GND_6), U9.29 (GND_7), U9.31 (GND_8), U9.32 (GND_9), U9.35 (GND_10), U9.43 (GND_11), U9.44 (GND_12), U9.46 (GND_13), U9.47 (GND_14), U9.53 (GND_15), U9.54 (GND_16), U9.56 (GND_17), U10.3 (VSSA), U10.5 (VSSD), U10.15 (VSSSPK), U10.21 (EXP), U11.7 (GND), U12.1 (SHELL), U12.2 (SHELL), U12.3 (SHELL), U12.4 (SHELL), U12.A1B12 (GND), U12.B1A12 (GND), U13.3 (GND), U14.5 (GND), U14.8 (GND), U14.9 (GND); also elsewhere on the board
LTE_PWR: Q1.1 (B); also elsewhere on the board
unnamed: C47.2, C48.2, L7.2
unnamed: C48.1, E1.1, L3.2
unnamed: D4.1 (K), R30.1
unnamed: D5.1 (K), R31.1
unnamed: J6.1, U10.16 (SPKOUT-)
unnamed: J6.2, U10.14 (SPKOUT+)
unnamed: C28.1, MK1.2 (+), R26.1
unnamed: C29.1, MK1.1 (-), R27.2
unnamed: Q1.3 (C), SW3.1, U9.30 (PWRKEY)
unnamed: Q2.3 (C), R30.2
unnamed: Q3.3 (C), R31.2
unnamed: R28.2, U12.B5 (CC2)
unnamed: R29.2, U12.A5 (CC1)
unnamed: TP9.1, U9.51 (DBG_TXD)
unnamed: TP8.1, U9.2 (DIV_ANT)
unnamed: C28.2, U10.20 (MIC+)
unnamed: C29.2, U10.19 (MIC-)
unnamed: C32.2, C33.2, U10.13 (MOUT)
unnamed: C31.2, U10.18 (VREF)
unnamed: U9.39 (RXD), U11.2 (A1)
unnamed: U9.38 (TXD), U11.3 (A2)
unnamed: U9.42 (RI), U11.4 (A3)
unnamed: U9.40 (DTR), U11.5 (A4)
RI: U11.11 (B3); also elsewhere on the board
RP_RX: U11.12 (B2); also elsewhere on the board
RP_TX: U11.13 (B1); also elsewhere on the board
VSYS: C34.1, C35.1, D2.1 (K), U9.33 (VBAT_1), U9.34 (VBAT_2); also elsewhere on the board

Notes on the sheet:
LED MAP Status (Y/G): CHARGE/ACOK In Use (G): NETLIGHT No Connection (R): RP2040_STATUS Roaming (OJ): LTE_STATUS
orange
AUDIO CODEC
green
BACK
LTE
SIM CARD
internal pull-up
close to ic
DK: GSB1C41110SSHR
ANTENNA
wider than 2mm
LTE USB

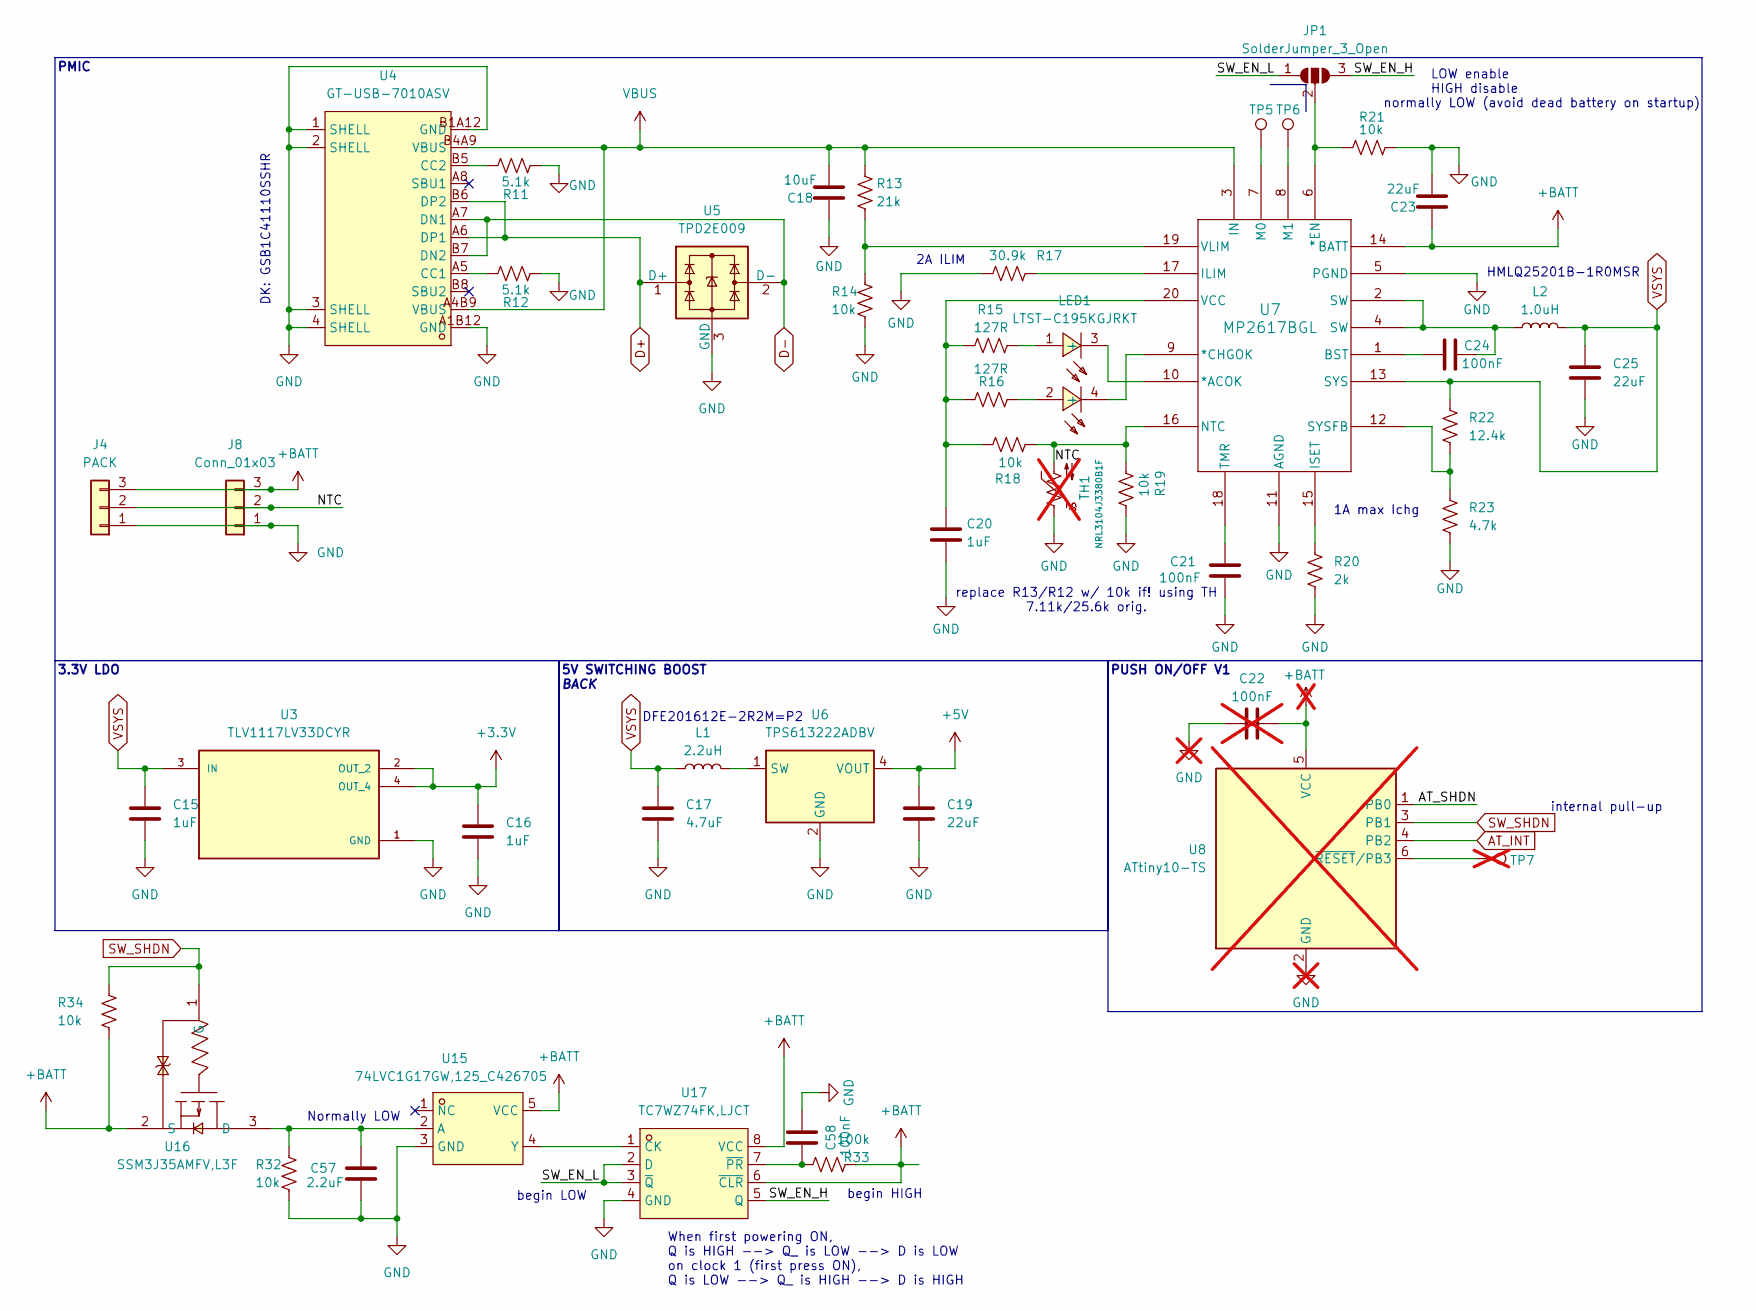
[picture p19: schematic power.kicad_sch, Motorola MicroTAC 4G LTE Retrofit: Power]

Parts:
C15, C16, C20: 1uF; C_0603_1608Metric; LCSC Part # C59782
C17: 4.7uF; C_0603_1608Metric; LCSC Part # C107368
C18: 10uF; C_0603_1608Metric; LCSC Part # C3039698
C19, C23, C25: 22uF; C_0603_1608Metric; LCSC Part # C86295
C21, C24, C58: 100nF; C_0603_1608Metric; LCSC Part # C1591
C22: 100nF; C_0603_1608Metric_Pad1.08x0.95mm_HandSolder; LCSC Part # C1591; not fitted
C57: 2.2uF; C_0603_1608Metric; LCSC Part # C100082
J4: PACK; MicroTAC Batt Contact
J8: Conn_01x03; PinHeader_1x03_P2.54mm_Vertical
JP1: SolderJumper_3_Open; SolderJumper-3_P1.3mm_Bridged12_Pad1.0x1.5mm_NumberLabels
L1: 2.2uH; IND_DFE2016_MUR; LCSC Part # C337893
L2: 1.0uH; IND-SMD_L3.0-W3.0-LS3.65; LCSC Part # C553992
LED1: LTST-C195KGJRKT; LED-ARRAY-SMD_0603-4P-L1.6-W1.5-BR-RD; LCSC Part C125104
R11, R12: 5.1k; R_0603_1608Metric; LCSC Part # C105580
R13: 21k; R_0603_1608Metric; LCSC Part # C137769
R14, R18, R19, R21, R32, R34: 10k; R_0603_1608Metric; LCSC Part # C98220
R15, R16: 127R; R_0603_1608Metric; LCSC Part # C137799
R17: 30.9k; R_0603_1608Metric; LCSC Part # C137744
R20: 2k; R_0603_1608Metric; LCSC Part # C105576
R22: 12.4k; R_0603_1608Metric; LCSC Part # C137798
R23: 4.7k; R_0603_1608Metric; LCSC Part # C99782
R33: 100k; R_0603_1608Metric; LCSC Part # C14675
TH1: NRL3104J3380B1F; MicroTAC Peripherals; not fitted
TP5, TP6: TestPoint; TestPoint_Pad_D1.0mm
TP7: TestPoint; TestPoint_Pad_D1.0mm; not fitted
U3: TLV1117LV33DCYR; SOT-223; PARTREV B; LCSC Part # C15578
U4: GT-USB-7010ASV; USB-C-SMD_G-SWITCH_GT-USB-7010ASV; LCSC Part C2988369
U5: TPD2E009; SOT-23; LCSC Part # C2871371
U6: TPS613222ADBV; SOT-23-5; LCSC Part # C2071163
U7: MP2617BGL; QFN-3x4_MP2617B_MNP
U8: ATtiny10-TS; SOT-23-6; LCSC Part # C2649376; not fitted
U15: 74LVC1G17GW,125_C426705; SOT-353_L2.1-W1.3-P0.65-LS2.3-BR; LCSC Part C426705
U16: SSM3J35AMFV,L3F; SOT-723_L1.2-W0.8-P0.80-LS1.2-BR; LCSC Part C5274156
U17: TC7WZ74FK,LJCT; US-8_L2.4-W2.1-P0.50-LS3.2-BL; LCSC Part C2652815

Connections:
+3.3V: C16.1, U3.2 (OUT_2), U3.4 (OUT_4); also elsewhere on the board
+5V: C19.1, U6.4 (VOUT); also elsewhere on the board
+BATT: C22.2, C23.2, J4.3, J8.3, R33.1, R34.1, U7.14 (BATT), U8.5 (VCC), U15.5 (VCC), U16.2 (S), U17.6 (~CLR), U17.8 (VCC); also elsewhere on the board
/Power/NTC: J4.2, J8.2, R18.1, R19.1, TH1.2, U7.16 (NTC)
/Power/SW_EN_H: JP1.3 (B), U17.5 (Q)
/Power/SW_EN_L: JP1.1 (A), U17.2 (D), U17.3 (~Q)
D+: U4.A6 (DP1), U4.B6 (DP2), U5.1 (D+); also elsewhere on the board
D-: U4.A7 (DN1), U4.B7 (DN2), U5.2 (D-); also elsewhere on the board
GND: C15.2, C16.2, C17.2, C18.2, C19.2, C20.2, C21.2, C22.1, C23.1, C25.2, C57.2, C58.1, J4.1, J8.1, R11.1, R12.1, R14.1, R17.2, R19.2, R20.2, R21.2, R23.1, R32.1, TH1.1, U3.1 (GND), U4.1 (SHELL), U4.2 (SHELL), U4.3 (SHELL), U4.4 (SHELL), U4.A1B12 (GND), U4.B1A12 (GND), U5.3 (GND), U6.2 (GND), U7.5 (PGND), U7.11 (AGND), U8.2 (GND), U15.3 (GND), U17.4 (GND); also elsewhere on the board
unnamed: C24.1, L2.1, U7.2 (SW), U7.4 (SW)
unnamed: JP1.2 (C), R21.1, U7.6 (*EN)
unnamed: LED1.1 (+), R15.2
unnamed: LED1.2 (+), R16.1
unnamed: TP7.1, U8.6 (~RESET/PB3)
unnamed: R12.2, U4.A5 (CC1)
unnamed: R11.2, U4.B5 (CC2)
unnamed: L1.2, U6.1 (SW)
unnamed: LED1.3 (-), U7.10 (*ACOK)
unnamed: LED1.4 (-), U7.9 (*CHGOK)
unnamed: C24.2, U7.1 (BST)
unnamed: R17.1, U7.17 (ILIM)
unnamed: R20.1, U7.15 (ISET)
unnamed: TP5.1, U7.7 (M0)
unnamed: TP6.1, U7.8 (M1)
unnamed: R22.1, R23.2, U7.12 (SYSFB)
unnamed: C21.1, U7.18 (TMR)
unnamed: C20.1, R15.1, R16.2, R18.2, U7.20 (VCC)
unnamed: R13.1, R14.2, U7.19 (VLIM)
unnamed: C57.1, R32.2, U15.2 (A), U16.3 (D)
unnamed: U15.4 (Y), U17.1 (CK)
unnamed: C58.2, R33.2, U17.7 (~PR)
SW_SHDN: R34.2, U8.3 (PB1), U16.1 (G); also elsewhere on the board
VBUS: C18.1, R13.2, U4.A4B9 (VBUS), U4.B4A9 (VBUS), U7.3 (IN)
VSYS: C15.1, C17.1, C25.1, L1.1, L2.2, R22.2, U3.3 (IN), U7.13 (SYS); also elsewhere on the board

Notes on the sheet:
Normally LOW
internal pull-up
DK: GSB1C41110SSHR
normally LOW (avoid dead battery on startup)
2A ILIM
DFE201612E-2R2M=P2
1A max Ichg
LOW enable HIGH disable
BACK
3.3V LDO
HMLQ25201B-1R0MSR
PUSH ON/OFF V1
begin HIGH
begin LOW
PMIC
5V SWITCHING BOOST
When first powering ON, Q is HIGH --> Q_ is LOW --> D is LOW on clock 1 (first press ON), Q is LOW --> Q_ is HIGH --> D is HIGH
replace R13/R12 w/ 10k if! using TH 7.11k/25.6k orig.

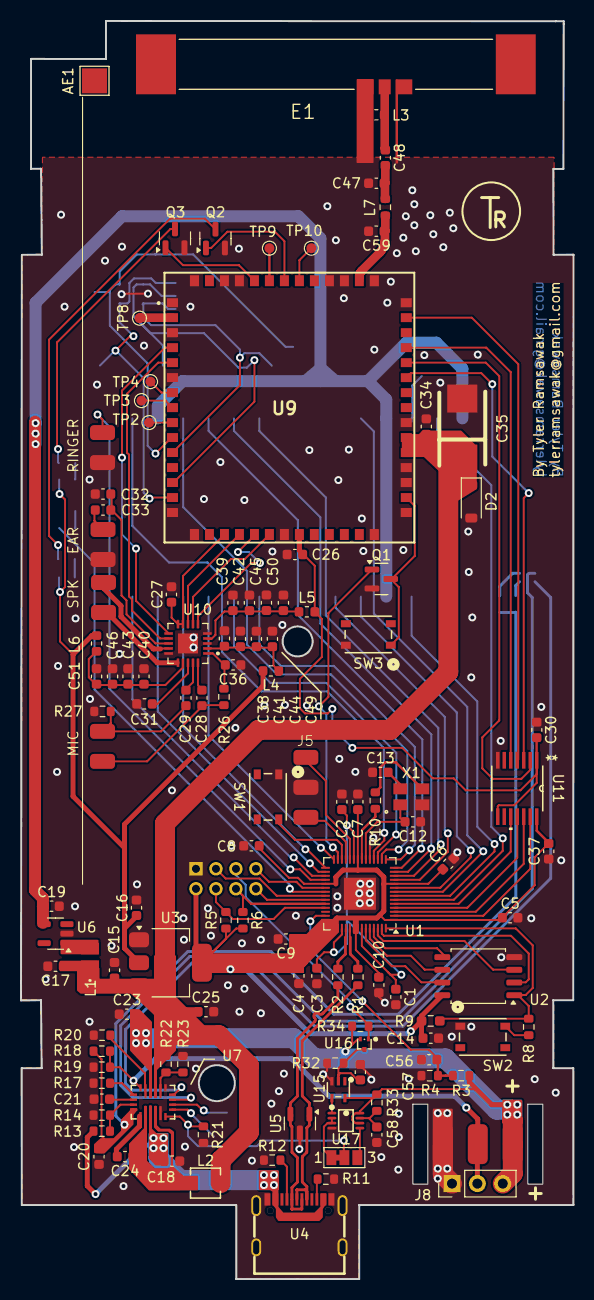
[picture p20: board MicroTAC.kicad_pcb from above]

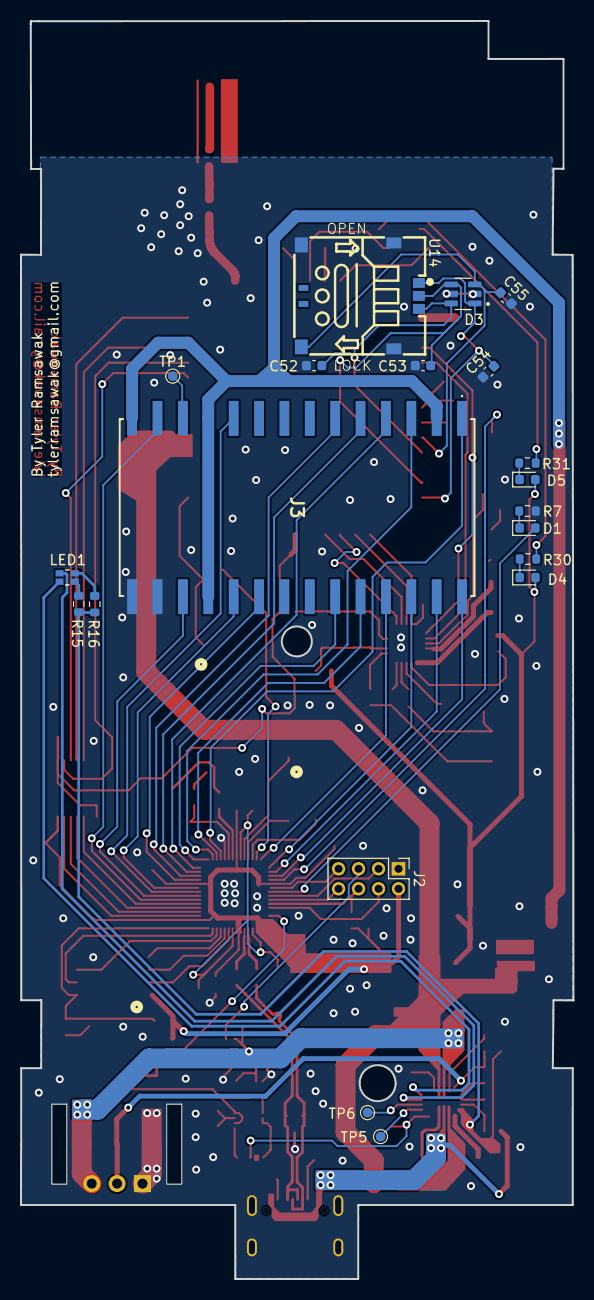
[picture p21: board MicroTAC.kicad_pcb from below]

Board: 4 copper layers, 55.3 x 125.9 mm, 142 parts (20 on the bottom side), 125 nets.
